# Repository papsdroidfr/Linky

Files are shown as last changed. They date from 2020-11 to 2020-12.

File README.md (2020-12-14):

# Linky

Affichage déporté et auto-alimenté compteur linky - DIY

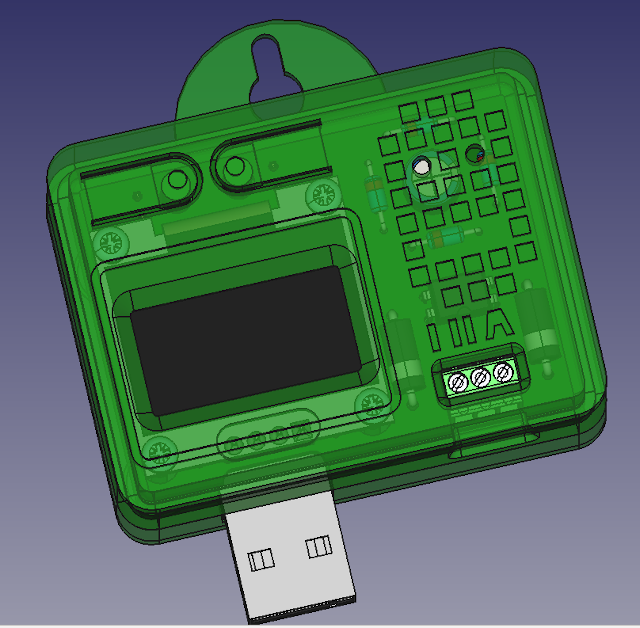
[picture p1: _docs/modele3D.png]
modele3D


Ce projet permet de déporter l'affichage d'un compteur linky sur un petit écran OLED piloté par un mico-controleur PybStick26 lite si peu gourmand en energie qu'il peut être auto-alimenté directement par la prise TIC du compteur Linky sans aucune source 220v. Cela permet de voir en temps réèl la consommation en W, les indexes WH, les informations de contrat etc ... sans avoir à descendre dans son garage ou dans le local dans lequel le compteur est installé.

Notice de montage pas à pas sur https://www.papsdroid.fr/post/linky

## Prise TIC du compteur

Il faut enlever le cadre vert clipsable (vous avez parfaitement le droit): la prise TIC se situe en bas à droite. Il s'agit d'un bornier sans vis composé de 3 sorties: I1, I2 et A. On peut y loger des fils rigides de section 1 à 1,5mm dedans.

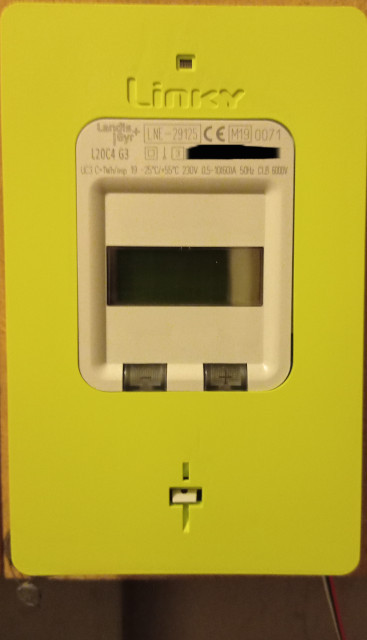
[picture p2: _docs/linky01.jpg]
compteur linky

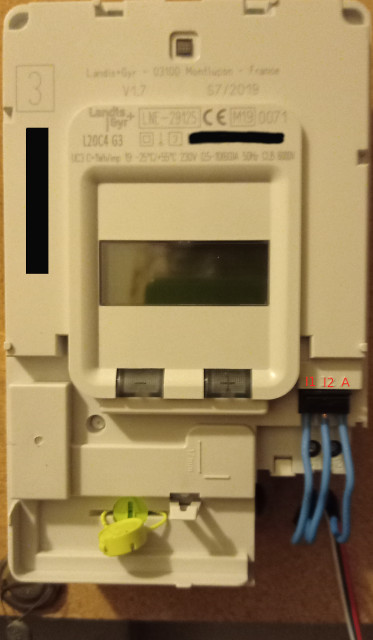
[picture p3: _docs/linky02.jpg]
compteur linky


Les informations du compteur sont transmises via les prises I1 et I2 sous la forme d'un protocole UART 1200 bauds  sur une porteuse 50khz. Une trame est composée d'informations de 10 bits dont 1 bit start, 7 bits qui codent un caractère ASCII, 1 bit de parité et 1 bit stop. Le décodage UART va consister à récupérer les 7 bits composant un caractère ASCII et de stocker le tout dans un tampon que l'on va lire et décoder.

Entre les prises I1 et A on peut récupérer une alimentation sous forme de courant alternatif 50khz qui oscille entre -16 et +16v (avec des pics à 20V, selon la longeur du câble que vous allez utiliser). Pour alimenter un micro-contrôleur qui exige du courant continu il faudra redresser, filrer, et réguler cette alimentation, mais elle est **limité à 130mw**: il sera impossible par exemple d'espérer faire démarrer un Raspberry pi  (même un piZero) avec si peu de puissance.

Plus d'information techniques sur la [prise TIC](https://www.enedis.fr/sites/default/files/Enedis-NOI-CPT_54E.pdf)

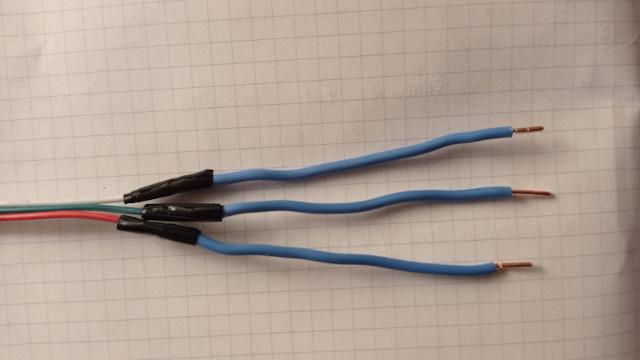
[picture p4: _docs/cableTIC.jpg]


Concernant le câble, soit vous utilisez un câble monobrin (fils durs) de section 1mm et colorés, comme par exemple des câbles bons marchés téléphoniques ou d'alarme, soit vous utilisez une nappe souple mais il faudra souder les extremités sur des câbles durs (ce que j'ai fait): j'ai utilisé 5m de nappe souple bon marché utilisée pour alimenter des rubans de leds par exemple et ça fonctionne très bien.

## Circuit électronique
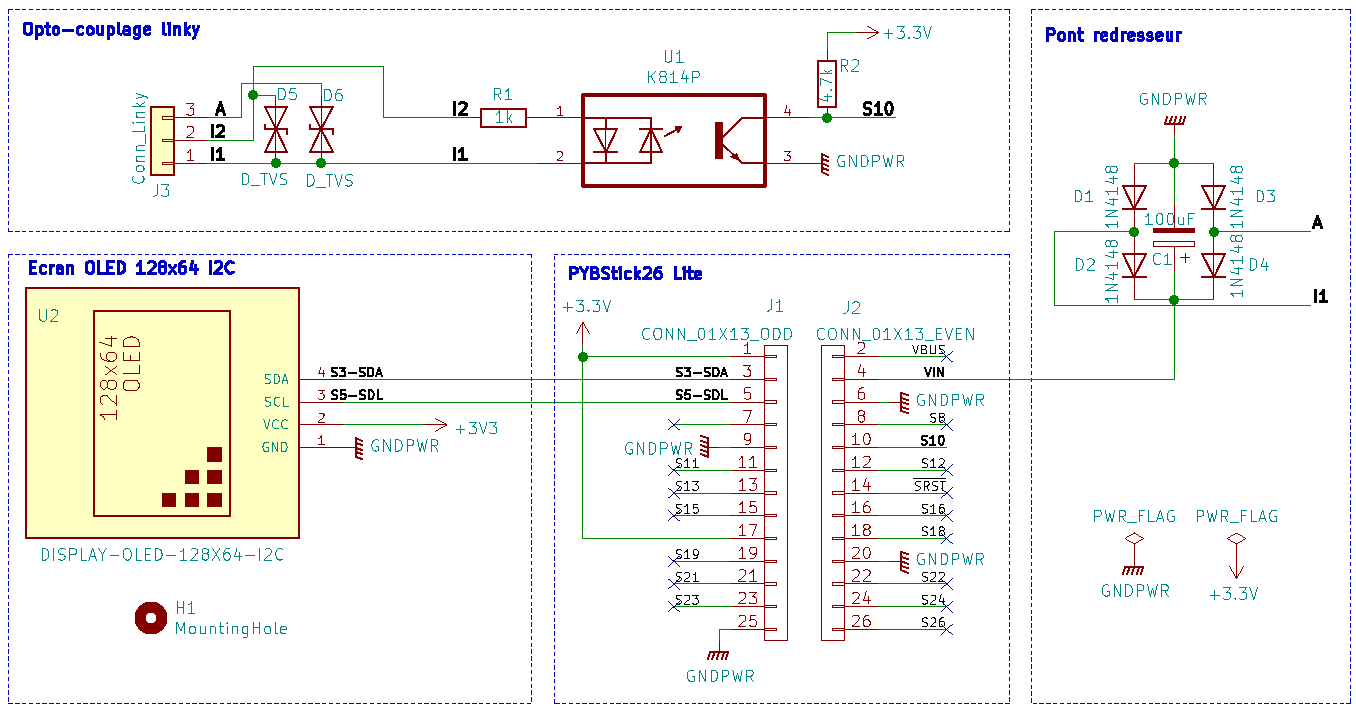
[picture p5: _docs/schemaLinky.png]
schéma


L'électronique se compose de 4 blocs principaux.
* **Opto-couplage du signal I1, I2**: un optocoupleur vishay K814P va permettre de récupérer le signal I1, I2 avec un jeux de résistances pour ne pas saturer le transistor. Nous ajoutons des diodes transil bidirectionnelles (16v DO-15) entre I1,I2 puis entre I1,A afin d'y limiter la tension à 16V. On peut faire sans mais elle sont là pour protéger des surtensions (j'ai déjà cramé une PYBStick à cause des pics de tensions qui grimpaient à 20v parfois sur la TIC de mon compteurlinky). Il vaut mieux les mettre...
* **PYBStick26**: un modèle Lite est suffisant. On récupère le signal pull-up de l'opto-coupleur sur la PIN S10 qui gère l'entrée Rx UART
* **Pont-redresseur**: 4 diodes 1N4148 vont redresser le signal entre I1 et A, puis une capactié 100uF va filtrer et lisser le signal. Avec en plus la diode Transil entre I1 et A on obtient ainsi un signal propre lissé à 16v max. La PYBStick étant équipée de son propre régulateur de tension, elle accepte en entrée Vin jusqu'à 18v: ce pont redresseur filtré est parfait pour l'alimenter.
* **Ecran OLED**: un écran OLED I2C 0.96" 128*64 avec 4 broches est relié en I2C à la PYBStick26: ces écrans consomment très peu de puissance, bien moins qu'un écran LCD: ils sont parfaits pour notre utilisation à puissance limitée.

Le micro-contrôleur **PYBStick26** est bien adapté pour ce projet. Tout d'abord cocorico je rapelle qu'il s'agit d'un micro-contrôleur **made in France** que l'on peut trouver pour quelques € [ici](https://shop.mchobby.be/fr/micropython/1830-pybstick-lite-26-micropython-et-arduino-3232100018303-garatronic.html). Un modèle Lite est suffisant pour ce projet. Ce micro-contrôleur programmable en micro-python est équipé de connecteurs UART et I2C qui vont permettre de décoder le signal UART du compteur Linky et de communiquer avec un écran OLED I2C. Il intégre aussi son propre régulateur interne et accepte d'être alimenté aussi bien en 5v qu'en 18v max, donc pas besoin de rajouter un étage de régulation. La PYBStick26 est aussi équipée en interne de deux petits boutons poussoirs que l'on peut programmer pour son usage personnel. Enfin cerise sur le gâteau: il consomme à peine 20mA sous 5V on reste en dessous des 130mw max.

Petite présentation de la PYBStick26: c'est [par ici](https://www.papsdroid.fr/post/pybstick).

### Bilan du matériel nécessaire:
* 1 PYBStick26 Lite
* 2 pin header mâles 13 pins 2,54mm (ne pas utiliser les header femelles qui sont fournies avec la PYBStick26).
* 1 bornier à vis type phoenix, 3 pin 2.54mm pour racorder les 3 fils de la prise TIC (I1, I2, A)
* 2 diodes transil 16v DO-15
* 1 opto-coupleur Vishay K814P
* 1 résistance 1k
* 1 résistance 4,7k
* 4 diodes 1N4148
* 1 condensateur électrolyte polarisé 100uF 25V
* 1 écran OLED I2C 0.96" 128*64 pixels, équipé de 4 pin mâles 2.54mm

Le circuit est facilement réalisable sur une platine d'essai sans soudure de type breadboard. Mais attention si vous soudez les pin header mâles sur la pybstick vous ne pourrez plus souder l'écran OLED sur le circuit imprimé prévu ... Usage à réserver en mode prototype.

Pour faire des tests et écrire le programme, j'ai relié ma PYBtick26 sur le port USB d'un Raspberry pi3b+ que j'ai laissé dans ma cuisine. Je me suis ensuite connecté en SSH depuis mon bureau sur ce Rapsberry pi pour pouvoir écrire et tester les programmes micro-python de la PYBStick26. Ceci ma évité d'avoir à tirer un immense câble depuis mon compteur linky (proche de ma cuisine en fait) jusqu'à mon bureau: très pratique... Bien entendu pour l'utilisation finale on n'a plus besoin du Raspberry pi.

## programme de test pour récupérer la trame communiquée par prise TIC

Votre PYBStick26 doit être reliée à un ordinateur via sa prise USB pour voir sur un écran la trame communiquée par la prise TIC.
Dans ce cas il n'est pas nécessaire d'avoir le pont-redesseur, ni l'écran OLED, ni les diodes Transil pour cet essai,  puisque la PYBStick26 sera alimentée par la prise USB de L'ordi. (moi j'utilise un petit raspberry pi 3b+ auquel j'accède en SSH tranquillement depuis mon bureau).

ce programme est disponible dans les sources /tests
```python
#main.py -- put your code here!

import pyb
from time import sleep

print('Linky start')

# pybstick lite à 48MHz, config UART
pyb.freq(48000000)
buffer_size = 128
info = pyb.UART(2, 1200, bits=7, parity=0, stop=1, timeout=0)

def lecture_linky():
    while True:
        tampon=info.read(buffer_size)
        print('tampon lu: ', tampon)
        sleep(0.5)

try:
    lecture_linky()
except KeyboardInterrupt:
    print('Bye')
```

En vous connectant sur l'interpeteur REPL (screen /dev/ttyACM0 sous un système linux) depuis votre PC auquel la PYBSTICK26 est reliée, vous devez voir apparaître les caractères ASCII de la trame TIC lue dans le tampon:
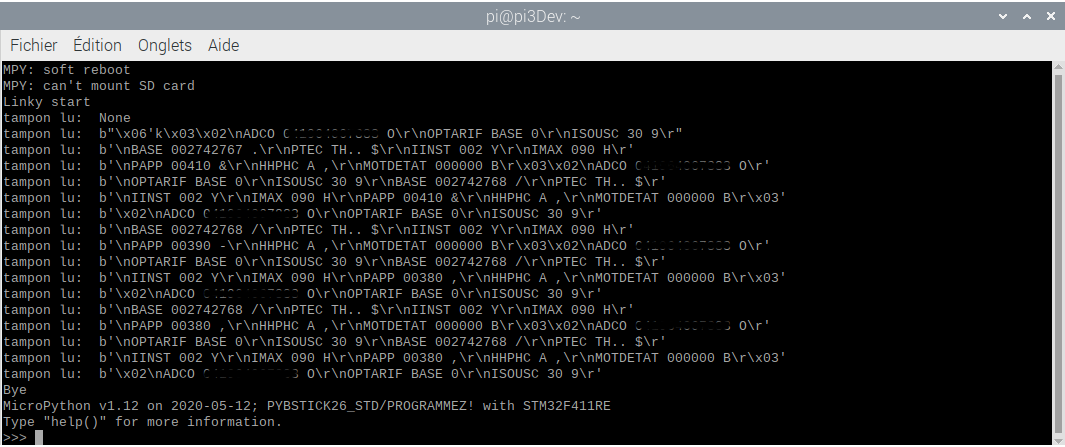
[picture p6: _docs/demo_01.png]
trameTIC


Si vous ne récoltez que du "None" dans le tampon c'est que l'opto-couplage ne fonctionne pas: vérifiez bien les branchements. Si vous utilisez un autre opto-coupleur que le Vishay K814P il se peut qu'il soit plus ou moins vite saturé, dans ce cas il faut y aller à tâton avec les résistances: essayez par exemple 1.2k au lieu de 1k et 3.3k ou 2.2k au lieu des 4.7k pour le pull-up en sortie du transisor. Vous pouvez inverser I1 et I2 dans le montage ça n'a aucune importance.

## programme pour affichage sur écran OLED

Pour utiliser le dispositif complet auto-alimenté par la prise TIC, il faut d'abord réaliser le montage électronique complet, et ne surtout pas oublier les diodes transil qui vont protéger des surtensions (il y a des pics tueurs  à 20v !). Bien entendu ne reliez rien d'autre que la prise TIC (I1, I2, et A) sur votre circuit: **n'allez surtout pas y mettre du 220V !** les diodes claqueraient fort mais vous vous métriez surtout en danger mortel d'électrocution!

Pour communiquer avec l'écran OLED il faut installer toutes les dépendances : déposez bien tous les fichiers fournis dans **/microPython** à la racine de votre PYBStick (inutile de recréer le répertoire /microPython)

Le script va lire en boucle la trame TIC stockée dans un tampon. il faut lire la doc de la prise TIC pour comprendre comment décoder cette trame mais ce n'est pas sorcier. Chaque indexe est fourni après un saut de ligne ('\n'), ensuite on a la valeur de l'indexe après un espace, et ainsi de suite. Chaque indexe a une taille qui lui est propre. Il suffit de stocker dans un dictionnaire les idexes que l'on veut rechercher dans le tampon, avec leur taille on sait où récupérer les valeurs lorsque l'index est repéré dans le tampon: le tour est joué.

Les deux boutons de la PYBStick26 sont programmés pour 
* modifier le contraste (100%, 50%, 25%, Off) si vous ne voulez pas qu'il reste allumé à 100% 7J/7 24h/24.
* faire défiler deux écrans: l'un qui affiche les données de puissance en temps réel, et un autre qui affiche les données contractuelles.

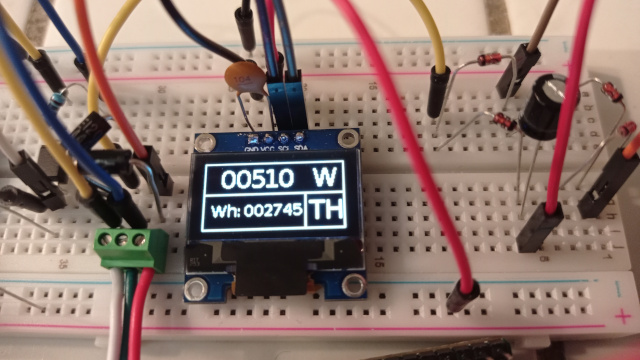
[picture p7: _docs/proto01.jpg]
prototype


## Usage ludique et instructif !

L'utlisation est très ludique est instructive. Allumez un lumière et vous verrez l'impact immédiat en W: une led va consommer 10W tandis qu'une ampoule à filament va brûler 50 à 80W!. Allumer votre télé, un ordinateur et plusieurs centaines de W se rajoutent, voire un bon millier s'il y a un qui s'amuse dans sa chambre en full HD 4k en faisant hurler tous les ventilateurs de sa carte graphique. Le four électrique, bouilloire, micro-onde en marche, et le compteur s'affole avec plusieurs milliers de W, et retombe aussitôt les appareils étteints. Je trouve ça super rigolo est instructif,c'est un très bon moyen de mieux consommer si on se rend compte en temps réel de sa consommation.

# Circuit imprimé (PCB)

Les composants peuvent être soudés sur une petite platine d'essai, mais un PCB a été conçu sous KiCad, il est à utiliser avec le boîtier imprimé 3D.
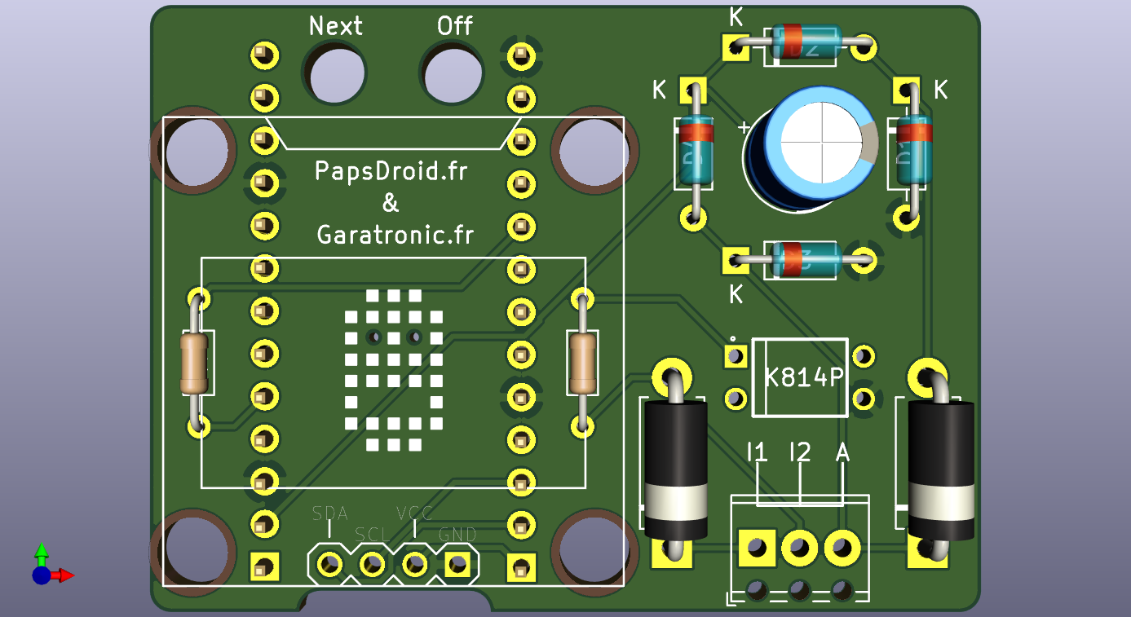
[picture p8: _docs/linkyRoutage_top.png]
PCB


Les fichiers GERBER nécessaires à la fabrication de ce circuit imprimé sont disponibles dans **/GERBER/GERBER_linky.zip** de ce Github.

Notice de montage pas à pas à consulter sur https://www.papsdroid.fr/post/linky

Il faut d'abord souder les composants du pont redresseur (attention au sens des diodes 1N4148 et de la capactié), l'opto-coupleur (attention au sens), les résistances (valeur sérigraphiées sur le PCB), les 2 diodes transil (peu importe le sens car elles sont bidirectionnelles), le connecteur phoenix (dans le bon sens: on doit pouvoir y brancher les fils de la prise TIC depuis l'extérieur de la carte). Ensuite, attention à veiller à **souder d'abord** les deux pin header mâle à positionner **sous** la carte (soudures au dessus donc), avant de souder l'écran OLED (sinon une fois l'écran soudé vous ne pouvez plus souder les 2 rangées de pin header...). Vous pouvez vous aider d'une breadboard pour les souder bien droits et perpendiculaires à la cate. Enfin, il faut **souder en tout dernier la PYBStick26** sur les pinheader déjà soudés à la carte, et dans le bon sens surtout: les deux boutons poussoirs doivent être orientés vers les deux trous "Off" et "Next".

# Boîtier imprimé 3D

Ce boîtier réalisé sur mesure sous FreeCad est composé de deux parties clipsables haute et basse, sur laquelle viennent se fixer le PCB et les réhausses de bouton poussoir.

modélisation du PCB avec les composants
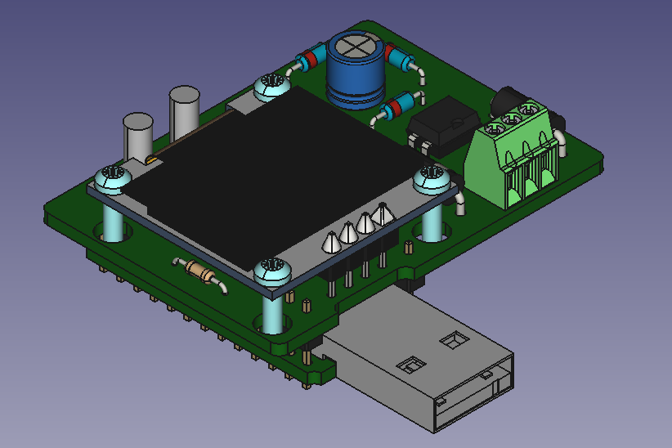
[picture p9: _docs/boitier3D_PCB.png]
boitier3D_PCB


partie basse du boîtier
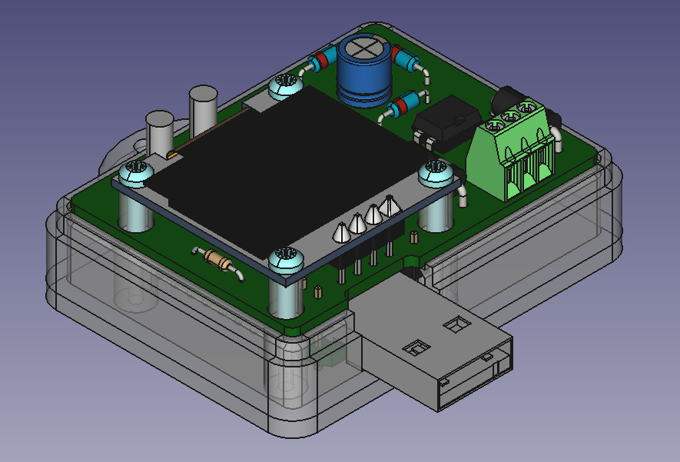
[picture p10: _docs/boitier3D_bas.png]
boitier3D_bas


boitier dans son intégralité avec la visserie.
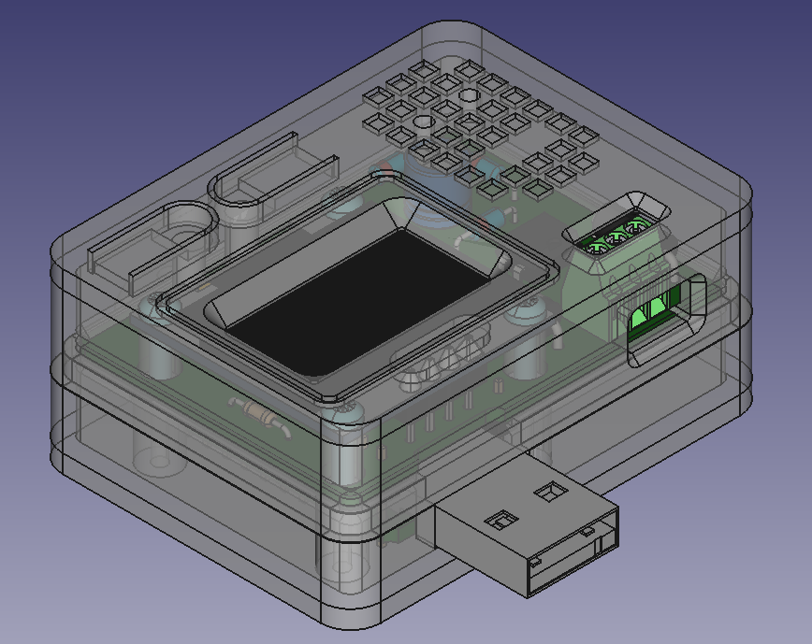
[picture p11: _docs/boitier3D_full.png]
boitier3D_full


Si vous avez une imprimante 3D vous pouvez utiliser les 3 fichiers STL dans le dossier /FreeCad de ce Github:
* **FreeCad/linky_display_coque_basse.stl**: partie basse du boîtier
* **FreeCad/linky_display_coque_haute.stl**: partie haute
* **FreeCad/linky_display_rehausse_boutons.stl**: réhausses de bouton poussoir.

L'assemblage est très simple, pas besoin d'explication ;-)

Quand vous branchez les fils I1, I2 et A de la prise TIC au système: **veillez à ne pas vous tromper de sens**, les indications sont sérigraphiées sur le circuit imprimé et apparaissent en relief sur le boîter.

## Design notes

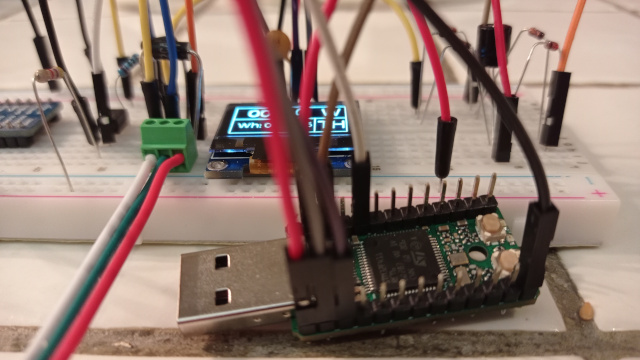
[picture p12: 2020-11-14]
_docs/proto02.jpg

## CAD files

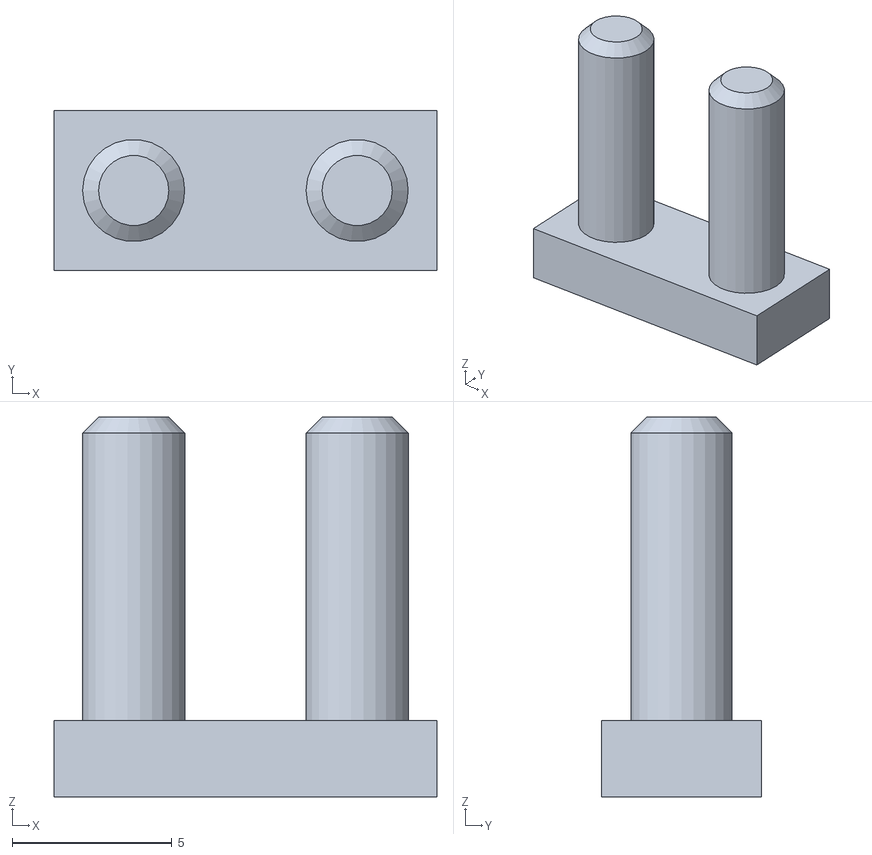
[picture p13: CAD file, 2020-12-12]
FreeCad/linky_display_rehausse_boutons.stl
12.0 x 5.00 x 11.9

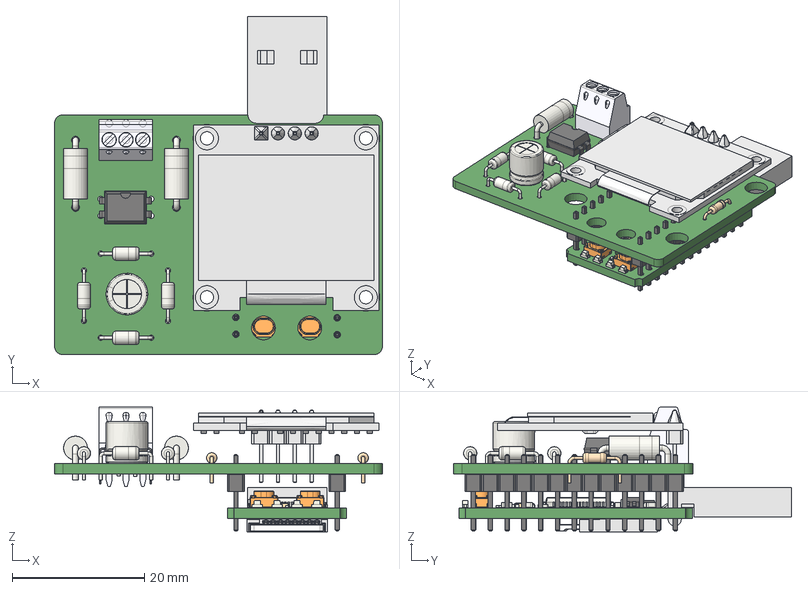
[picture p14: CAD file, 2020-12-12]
FreeCad/boitier_linky.FCStd
49.5 x 51.1 x 18.8 mm
0.96" OLED v3
mpt_0.5-3-2.54
DIP-4_W7.62mm

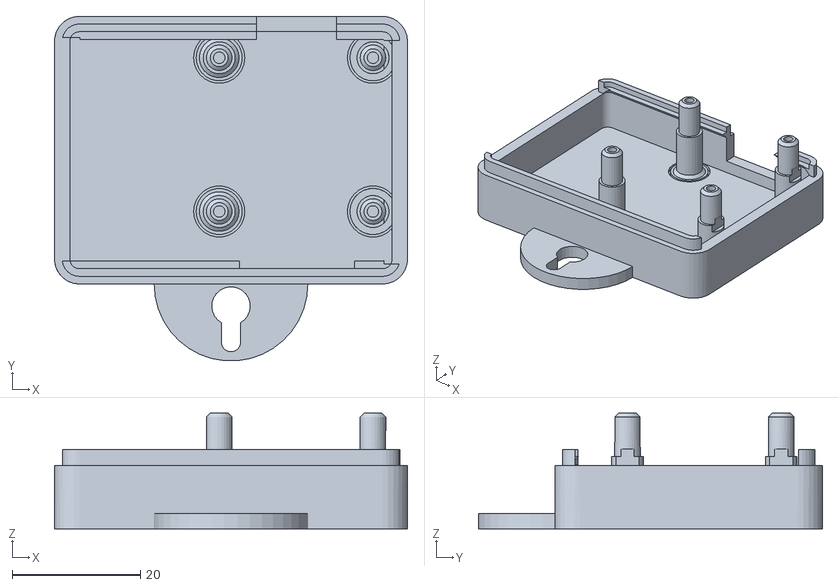
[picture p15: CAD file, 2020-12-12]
FreeCad/linky_display_coque_basse.stl
55.1 x 53.8 x 18.1

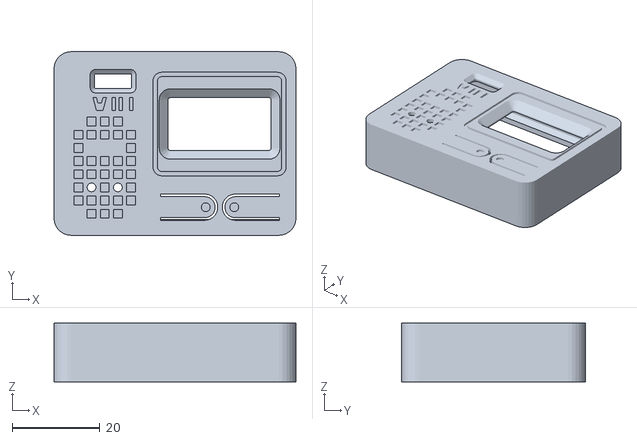
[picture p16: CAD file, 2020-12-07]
FreeCad/linky_display_coque_haute.stl
55.1 x 41.8 x 13.4

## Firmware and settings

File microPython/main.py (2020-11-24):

# main.py -- put your code here!

import pyb, select, ssd1306
from machine import I2C, Pin
from pyb import ExtInt
from time import sleep, sleep_ms
from fdrawer import FontDrawer

_VERSION = 'v1.35 2020-11-24'


class Application:
    ''' appli principale '''
    def __init__(self):
        pyb.freq(48000000)           # pybstick lite 48MHz pour autoalimentation sur compteur Linky
        self.i2c=I2C(1, freq=400000) # init bus i2c 400KHz
        self.info = pyb.UART(2, 1200, bits=7, parity=0, stop=1, timeout=0)
        self.buffer_size = 128

        # initialisation dictionnaire index linky  'INDEXE' : [taille, 'unité', 'valeur']
        self.idx = {'HCHC':   [6,'Wh','xxxxx'], # indexe heure creuses (Wh)
                    'HCHP':   [6,'Wh','xxxxx'], # indexe heures pleines (Wh)
                    'BASE':   [6,'Wh','xxxxx'], # indexe base (Wh)
                    'PAPP':   [5,'W','xxxxx'],  # puissance apparante (W)
                    'ISOUSC': [2,'A','xx'],     # intensitée souscrite (A)
                    'PTEC':   [2,'','xx'],      # période tarrifaire en cours
                    'OPTARIF':[4,'','xxxx'],    # option tarrifaire
                   }

        # Initialisation afficheur
        self.afficheur=Afficheur_i2c(self.i2c)

    def print_idx(self):
        ''' print les indexes '''
        str = 'indexes lus: '
        for idx in self.idx:
            str = str + idx + ":" + self.idx[idx][2] + " | "
        print(str)

    def loop(self):
        ''' boucle principale de l'appli'''
        while True:
            tampon=self.info.read(self.buffer_size)  #tampon est un tableau de bytes
            #print('tampon lu:',tampon) # debug
            if tampon != None:         # décodage tampon dans le dictionnaire self.idx
                for index in self.idx:
                    x=tampon.find(b'\n'+index) #les indexes sont tjrs devant un \n
                    x_debut = x + len(index) + 2
                    x_end = x_debut + self.idx[index][0]
                    if x>=0 and x_end < len(tampon):
                        self.idx[index][2] = tampon[x_debut : x_end].decode()
            #self.print_idx() #debug

            if self.afficheur.etat:
                if self.afficheur.id_affichage == 0:
                    self.afficheur.display_w(self.idx)
                else:
                    self.afficheur.display_contrat(self.idx)


    def destroy(self):
        ''' destructeur '''
        print('Bye')
        self.afficheur.off() #extinction écran Oled


class Afficheur_i2c:
    def __init__(self, i2c):
        ''' constructeur'''
        self.oled = ssd1306.SSD1306_I2C(width=128, height=64, i2c=i2c, addr=0x3c, external_vcc=False)
        self.oled.init_display()
        self.oled.rotate(True)                     # rotation écran 180°
        self.nb_affichages = 2                     # nb d'affichages total
        self.id_affichage = 0                      # id affichage en cours
        self.contrastes =  [255, 128, 64, 0]       # contraste afficheur 100%, 50%, 25%, O%(Off)
        self.id_contraste = 0                      # par défaut contraste à 100%
        self.etat = True                           # True: affiché, False: éteind
        self.buttonOnOff = pyb.Switch()            # bouton user A pybstick: on/off écran OLED
        self.buttonOnOff.callback(self.switchContraste) # callback appelé avec bouton user A
        self.buttonAffichage = Pin( 'SW2', Pin.IN) # bouton user B: change l'affichage
        self.extint = ExtInt('SW2', ExtInt.IRQ_FALLING, Pin.PULL_NONE, self.switchAffichage) #callback bouton user B

    def switchAffichage(self, line):
        sleep_ms(50) # stabilisation 50 ms pour éviter faux rebonds
        if not(self.buttonAffichage.value()): # bouton tjrs enfoncé après stabilisation ?
            self.id_affichage = (self.id_affichage + 1) % self.nb_affichages
            print('affichage num:', self.id_affichage) #debug

    def switchContraste(self):
        ''' switch contraste écran OLED '''
        sleep_ms(50) # stabilisation 50 ms pour éviter faux rebonds
        if not(self.buttonOnOff.value()): # bouton tjrs enfoncé après stabilisation ?
            self.id_contraste = (self.id_contraste + 1) % len(self.contrastes)
            c = self.contrastes[self.id_contraste]
            print('set contraste:', c)
            self.oled.contrast(c)
            if c==0:
                self.etat = False
                self.off()      # extinction écran
            else:
                self.etat = True

    def off(self):
        ''' extinction éran oled'''
        self.oled.fill(0)
        self.oled.show()

    def display_cadres(self):
        ''' affichage des cadres '''
        # cadres
        self.oled.fill(0)
        self.oled.rect( 0, 0, 128, 64, 1 )
        self.oled.line( 92, 30, 92, 64, 1 )
        self.oled.line( 0, 30, 128, 30, 1 )

    def display_w(self, idx):
        ''' affichage puissance W '''
        self.display_cadres()
        fd = FontDrawer( frame_buffer=self.oled, font_name = 'vera_23' )
        fd.print_str(idx['PAPP'][2], 16, 5 )   # valeur PAPP
        fd.print_str(idx['PAPP'][1], 100, 5 )  # unite PAPP
        fd.print_str(idx['PTEC'][2], 96, 36 )  # valeur PTEC
        fd = FontDrawer( frame_buffer=self.oled, font_name = 'vera_15' )
        if idx['PTEC'][2] != 'TH' : #tarif heure creuse
            fd.print_str("HP:", 8, 30 )
            fd.print_str("HC:", 8, 46 )
            fd.print_str(idx['HCHP'][2], 35, 30 )  # valeur HCHP
            fd.print_str(idx['HCHC'][2], 35, 46 )  # valeur HCHC
        else: #tarif base
            fd.print_str('KWh', 8, 38 )
            fd.print_str(idx['BASE'][2], 44, 38 )  # valeur index base
        if self.etat: self.oled.show()

    def display_contrat(self, idx):
        ''' affichage données du contrat '''
        self.display_cadres()
        fd = FontDrawer( frame_buffer=self.oled, font_name = 'vera_23' )
        fd.print_str('CONTRAT', 8, 5 )
        fd.print_str(idx['PTEC'][2], 96, 36 )  # valeur PTEC
        fd = FontDrawer( frame_buffer=self.oled, font_name = 'vera_15' )
        fd.print_str('TARIF:', 8, 30 )
        fd.print_str('I(A):', 26, 46 )
        fd.print_str(idx['OPTARIF'][2], 54, 30 )  # option tarrifaire
        fd.print_str(idx['ISOUSC'][2], 54, 46 )   # intensité souscrite
        if self.etat: self.oled.show()


#--- script principal
print('linky start ', _VERSION)
appl=Application()

try:
    appl.loop()
except KeyboardInterrupt:
    appl.destroy()

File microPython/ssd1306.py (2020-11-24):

# MicroPython SSD1306 OLED driver, I2C and SPI interfaces
# 2020-11-24  adaptation papsDroid.fr

from micropython import const
import framebuf


# register definitions
SET_CONTRAST = const(0x81)
SET_ENTIRE_ON = const(0xA4)
SET_NORM_INV = const(0xA6)
SET_DISP = const(0xAE)
SET_MEM_ADDR = const(0x20)
SET_COL_ADDR = const(0x21)
SET_PAGE_ADDR = const(0x22)
SET_DISP_START_LINE = const(0x40)
SET_SEG_REMAP = const(0xA0)
SET_MUX_RATIO = const(0xA8)
SET_COM_OUT_DIR = const(0xC0)
SET_DISP_OFFSET = const(0xD3)
SET_COM_PIN_CFG = const(0xDA)
SET_DISP_CLK_DIV = const(0xD5)
SET_PRECHARGE = const(0xD9)
SET_VCOM_DESEL = const(0xDB)
SET_CHARGE_PUMP = const(0x8D)

# Subclassing FrameBuffer provides support for graphics primitives
# http://docs.micropython.org/en/latest/pyboard/library/framebuf.html
class SSD1306(framebuf.FrameBuffer):
    def __init__(self, width, height, external_vcc):
        self.width = width
        self.height = height
        self.external_vcc = external_vcc
        self.pages = self.height // 8
        self.buffer = bytearray(self.pages * self.width)
        super().__init__(self.buffer, self.width, self.height, framebuf.MONO_VLSB)
        self.init_display()

    def init_display(self):
        for cmd in (
            SET_DISP | 0x00,  # off
            # address setting
            SET_MEM_ADDR,
            0x00,  # horizontal
            # resolution and layout
            SET_DISP_START_LINE | 0x00,
            SET_SEG_REMAP | 0x01,  # column addr 127 mapped to SEG0
            SET_MUX_RATIO,
            self.height - 1,
            SET_COM_OUT_DIR | 0x08,  # scan from COM[N] to COM0
            SET_DISP_OFFSET,
            0x00,
            SET_COM_PIN_CFG,
            0x02 if self.width > 2 * self.height else 0x12,
            # timing and driving scheme
            SET_DISP_CLK_DIV,
            0x80,
            SET_PRECHARGE,
            0x22 if self.external_vcc else 0xF1,
            SET_VCOM_DESEL,
            0x30,  # 0.83*Vcc
            # display
            SET_CONTRAST,
            0xFF,  # maximum
            SET_ENTIRE_ON,  # output follows RAM contents
            SET_NORM_INV,  # not inverted
            # charge pump
            SET_CHARGE_PUMP,
            0x10 if self.external_vcc else 0x14,
            SET_DISP | 0x01,
        ):  # on
            self.write_cmd(cmd)
        self.fill(0)
        self.show()

    def poweroff(self):
        self.write_cmd(SET_DISP | 0x00)

    def poweron(self):
        self.write_cmd(SET_DISP | 0x01)

    def contrast(self, contrast):
        self.write_cmd(SET_CONTRAST)
        self.write_cmd(contrast)

    def invert(self, invert):
        self.write_cmd(SET_NORM_INV | (invert & 1))

    def show(self):
        x0 = 0
        x1 = self.width - 1
        if self.width == 64:
            # displays with width of 64 pixels are shifted by 32
            x0 += 32
            x1 += 32
        self.write_cmd(SET_COL_ADDR)
        self.write_cmd(x0)
        self.write_cmd(x1)
        self.write_cmd(SET_PAGE_ADDR)
        self.write_cmd(0)
        self.write_cmd(self.pages - 1)
        self.write_data(self.buffer)
        
    def rotate(self, flag):
        ''' rotation 180° '''
        if flag:
            self.write_cmd(SET_COM_OUT_DIR)  # mirror vertically
            self.write_cmd(SET_SEG_REMAP)    # mirror horizontally (64 rows)
        else:
            self.write_cmd(SET_COM_OUT_DIR | 0x08)
            self.write_cmd(SET_SEG_REMAP | 0x01)


class SSD1306_I2C(SSD1306):
    def __init__(self, width, height, i2c, addr=0x3C, external_vcc=False):
        self.i2c = i2c
        self.addr = addr
        self.temp = bytearray(2)
        self.write_list = [b"\x40", None]  # Co=0, D/C#=1
        super().__init__(width, height, external_vcc)

    def write_cmd(self, cmd):
        self.temp[0] = 0x80  # Co=1, D/C#=0
        self.temp[1] = cmd
        self.i2c.writeto(self.addr, self.temp)

    def write_data(self, buf):
        self.write_list[1] = buf
        self.i2c.writevto(self.addr, self.write_list)


class SSD1306_SPI(SSD1306):
    def __init__(self, width, height, spi, dc, res, cs, external_vcc=False):
        self.rate = 10 * 1024 * 1024
        dc.init(dc.OUT, value=0)
        res.init(res.OUT, value=0)
        cs.init(cs.OUT, value=1)
        self.spi = spi
        self.dc = dc
        self.res = res
        self.cs = cs
        import time

        self.res(1)
        time.sleep_ms(1)
        self.res(0)
        time.sleep_ms(10)
        self.res(1)
        super().__init__(width, height, external_vcc)

    def write_cmd(self, cmd):
        self.spi.init(baudrate=self.rate, polarity=0, phase=0)
        self.cs(1)
        self.dc(0)
        self.cs(0)
        self.spi.write(bytearray([cmd]))
        self.cs(1)

    def write_data(self, buf):
        self.spi.init(baudrate=self.rate, polarity=0, phase=0)
        self.cs(1)
        self.dc(1)
        self.cs(0)
        self.spi.write(buf)
        self.cs(1)
